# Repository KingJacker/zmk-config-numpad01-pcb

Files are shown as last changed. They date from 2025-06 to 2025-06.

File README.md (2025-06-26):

# NumPad01 - PCB

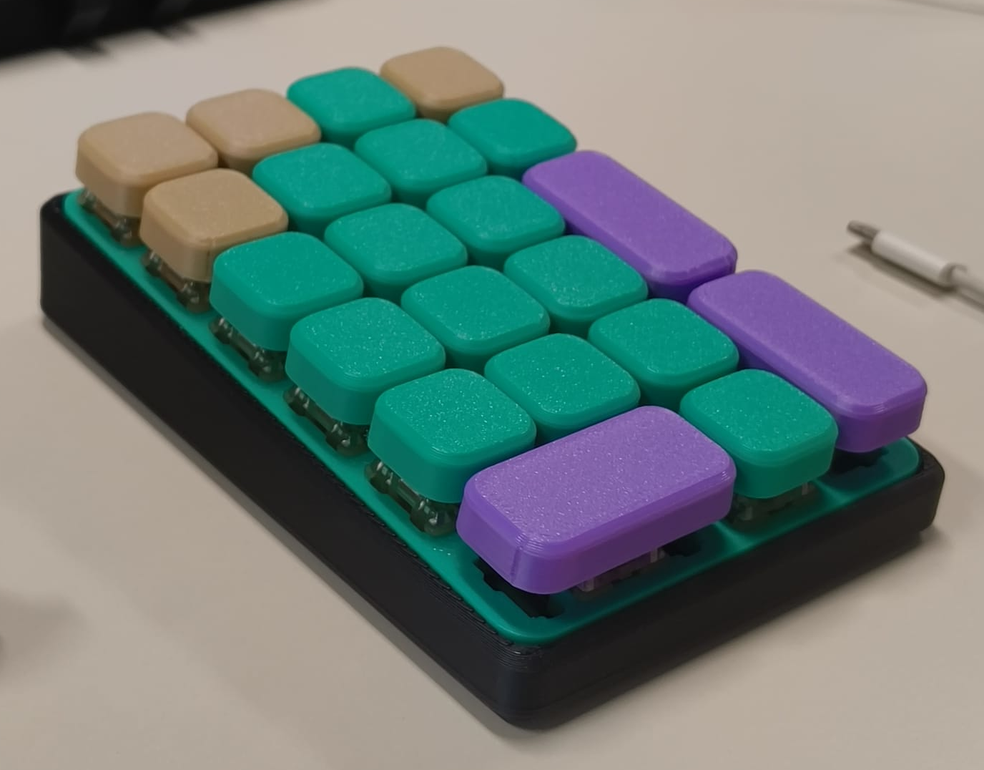
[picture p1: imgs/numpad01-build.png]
Example Build


This Repository outlines the requirements to build a custom Keyboard with an expanded Numpad layout.

## Hardware
This Keyboard is built using the NiceNanoV2 NRF Module to leverage its Bluetooth capabilities.

It is possible to Handwire this keyboard. Altough it was deisgned with a PCB in mind.

The KiCAD files can be found in [Numpad1](/Numpad1/).
The PCB is designed to use MX Hotswap sockets.

### Key Layout
The expanded Numpad layout looks as follows.\
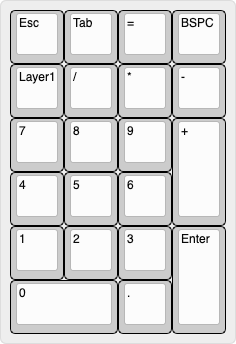
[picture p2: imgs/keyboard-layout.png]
Key Layout


### Wiring
In the following Diagram it is described which pins of the NiceNanoV2 are to be soldered to the Pads on the PCB.
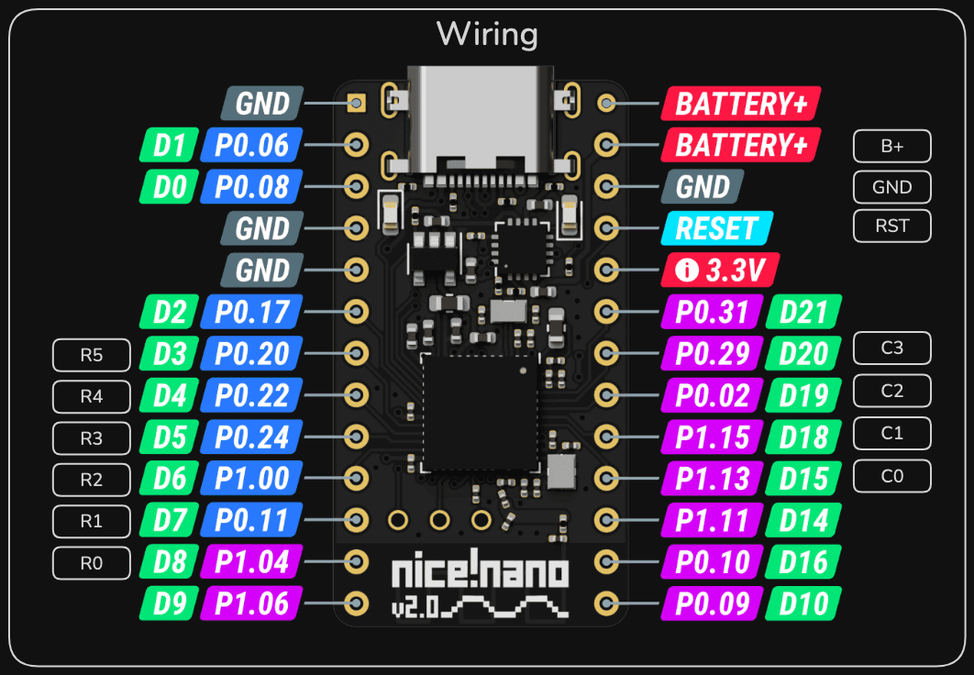
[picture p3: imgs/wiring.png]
Wiring Diagram


### Enclosure
I have deisgned a very slim Case for the PCB with just enough space for a small LiPo. You can find the OnShape Project at this [Link](https://cad.onshape.com/documents/f554f5fd452e23ddbeb69b48/w/c72bd622fd985e9e9cbd8d4f/e/263bace952513a244bd67565) or checkout the STEP files in [CAD/case](CAD/case).

###  Keycaps
This Keyboard has 21 Keys in Total.
| Amount | Type |
| --- |----- |
| 18 | 1u |
| 3 | 2u |

Custom Keycaps were designed for this project, while 3D printed Keycaps may not be optimal they surely look good.

You can find the OnShape Project at this [Link](https://cad.onshape.com/documents/af3d93fce92099b4708cc048/w/839bc3040b2b1ff49a4ff1b0/e/539817a75a59442267b910fb). Since I made multiple versions I won't upload them here.

## Firmware
To utilize the full Bluetooth capabilites of the NiceNanoV2 the ZMK firmware was used. This the Keymap of this config can be changed using [Nick's Keymap Editor](https://nickcoutsos.github.io/keymap-editor/).

You can find the latest firmware on the [Releases](https://github.com/KingJacker/zmk-config-numpad01-pcb/releases/tag/release) Page.

### Flashing
If you are starting out and haven't falshed anything to the NiceNanoV2, you need to short the RESET pin to GND twice in short succession while plugged in via USB C. 

The red light will Blink and a drive will appear on your computer with the name "NiceNanoV2". Simply drag the firmware file into drive. 

That's it, the drive will disappear and the NiceNanoV2 will reboot.

Once you have flashed this firmware you can always access the bootloader to update the firmware by pressing the Layer 1 Key and Plus at the same time.

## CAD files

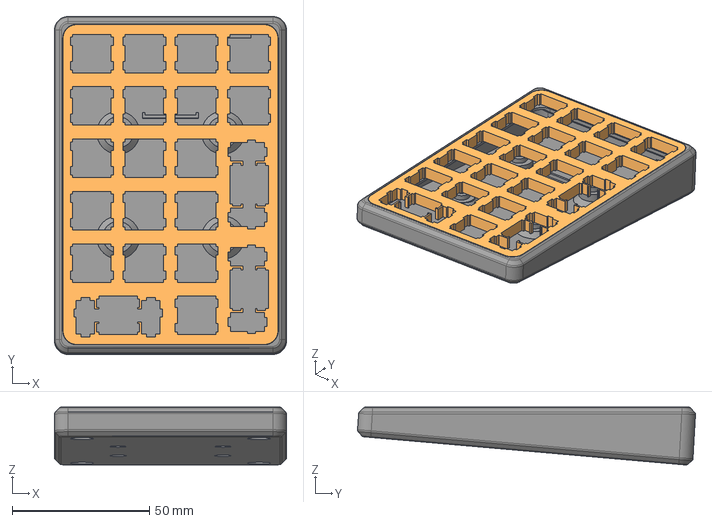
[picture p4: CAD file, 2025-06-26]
CAD/NumPad01-Case.step
84.4 x 122.9 x 21.1 mm
Plate

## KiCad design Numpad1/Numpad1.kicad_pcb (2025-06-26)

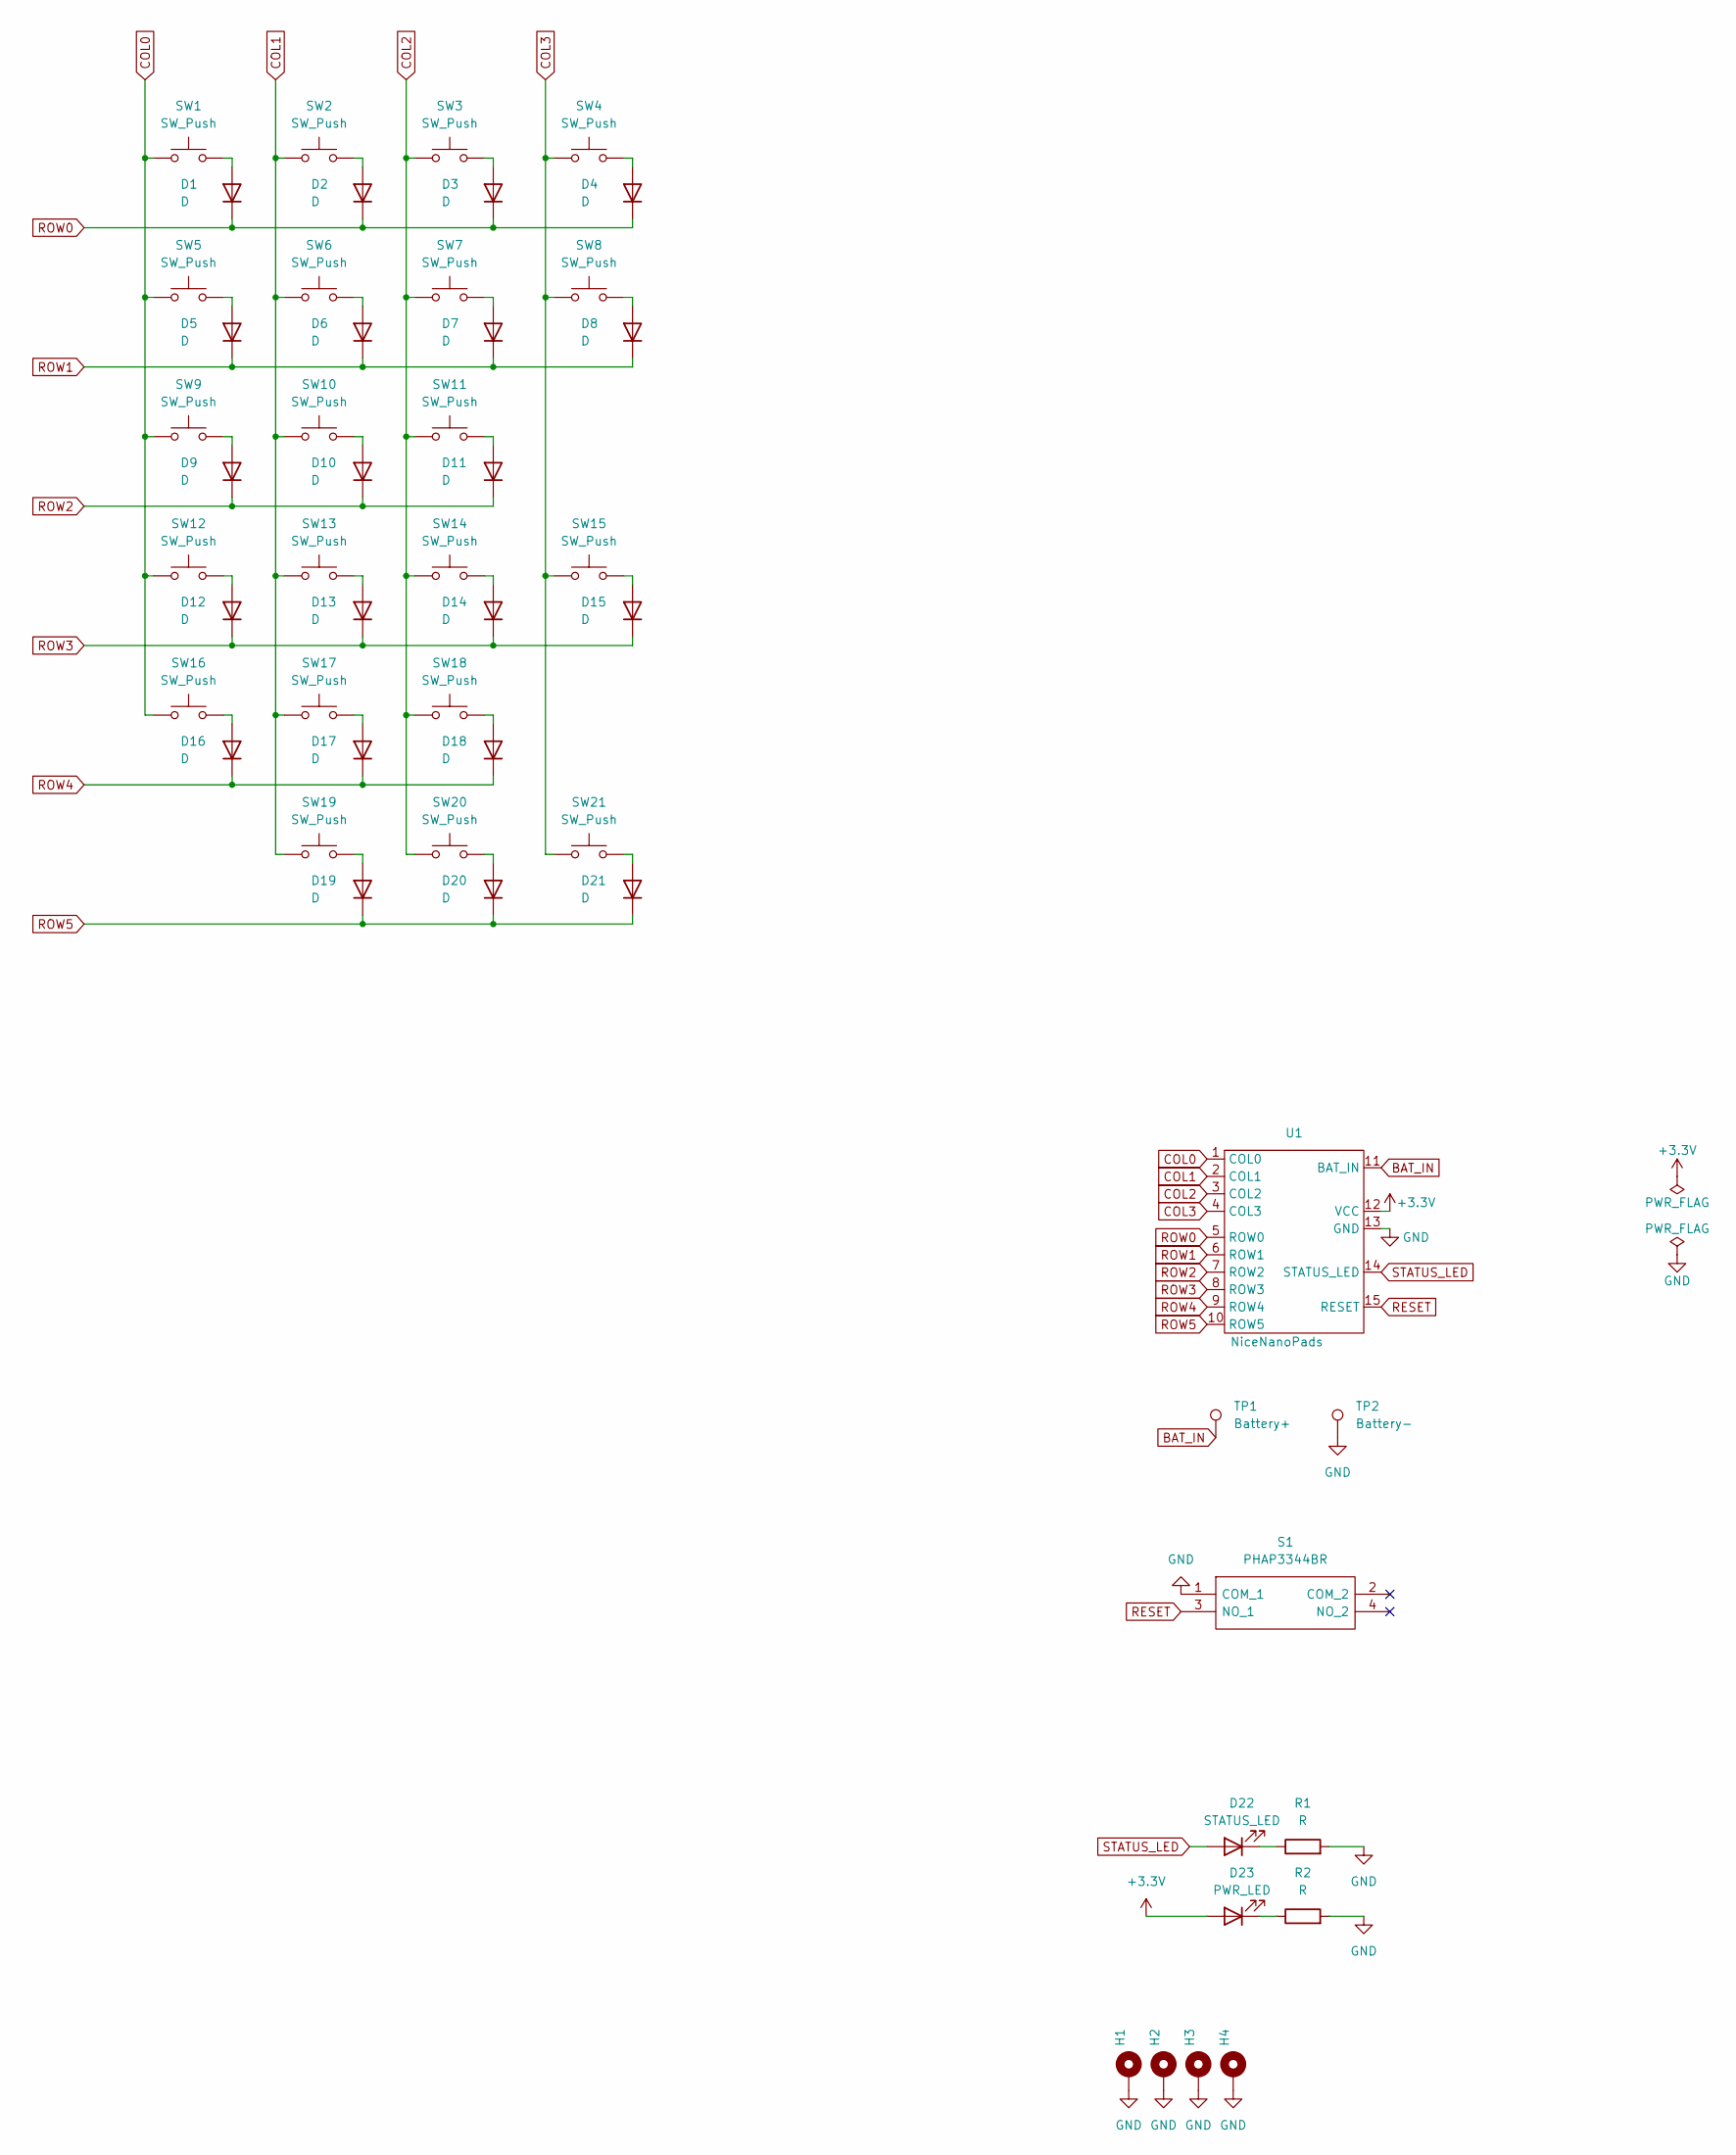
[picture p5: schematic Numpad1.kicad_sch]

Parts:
D1, D2, D3, D4, D5, D6, D7, D8, D9, D10, D11, D12, D13, D14, D15, D16, D17, D18, D19, D20, D21: D; D_SOD-123
D22: STATUS_LED; LED_0805_2012Metric_Pad1.15x1.40mm_HandSolder
D23: PWR_LED; LED_0805_2012Metric_Pad1.15x1.40mm_HandSolder
H1, H2, H3, H4: MountingHole_Pad; MountingHole_3.2mm_M3_DIN965_Pad
R1, R2: R; R_0805_2012Metric_Pad1.20x1.40mm_HandSolder
S1: PHAP3344BR; PTS526SM15SMTR2LFS; Mouser Part Number 642-PHAP3344BR
SW1, SW2, SW3, SW4, SW5, SW6, SW7, SW8, SW9, SW10, SW11, SW12, SW13, SW14, SW16, SW17, SW18, SW20: SW_Push; SW_Hotswap_Kailh_MX_1.00u
SW15, SW21: SW_Push; SW_Hotswap_Kailh_MX_2.00u_90deg
SW19: SW_Push; SW_Hotswap_Kailh_MX_2.00u
TP1: Battery+; TestPoint_Pad_D4.0mm
TP2: Battery-; TestPoint_Pad_D4.0mm
U1: NiceNanoPads

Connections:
+3.3V: D23.2 (A), U1.12 (VCC)
BAT_IN: TP1.1, U1.11 (BAT_IN); also elsewhere on the board
COL0: SW1.1, SW5.1, SW9.1, SW12.1, SW16.1, U1.1 (COL0)
COL1: SW2.1, SW6.1, SW10.1, SW13.1, SW17.1, SW19.1, U1.2 (COL1)
COL2: SW3.1, SW7.1, SW11.1, SW14.1, SW18.1, SW20.1, U1.3 (COL2)
COL3: SW4.1, SW8.1, SW15.1, SW21.1, U1.4 (COL3)
GND: H1.1, H2.1, H3.1, H4.1, R1.2, R2.2, S1.1 (COM_1), TP2.1, U1.13 (GND); also elsewhere on the board
unnamed: D1.2 (A), SW1.2
unnamed: D2.2 (A), SW2.2
unnamed: D3.2 (A), SW3.2
unnamed: D4.2 (A), SW4.2
unnamed: D5.2 (A), SW5.2
unnamed: D6.2 (A), SW6.2
unnamed: D7.2 (A), SW7.2
unnamed: D8.2 (A), SW8.2
unnamed: D9.2 (A), SW9.2
unnamed: D10.2 (A), SW10.2
unnamed: D11.2 (A), SW11.2
unnamed: D12.2 (A), SW12.2
unnamed: D13.2 (A), SW13.2
unnamed: D14.2 (A), SW14.2
unnamed: D15.2 (A), SW15.2
unnamed: D16.2 (A), SW16.2
unnamed: D17.2 (A), SW17.2
unnamed: D18.2 (A), SW18.2
unnamed: D19.2 (A), SW19.2
unnamed: D20.2 (A), SW20.2
unnamed: D21.2 (A), SW21.2
unnamed: D22.1 (K), R1.1
unnamed: D23.1 (K), R2.1
RESET: S1.3 (NO_1), U1.15 (RESET)
ROW0: D1.1 (K), D2.1 (K), D3.1 (K), D4.1 (K), U1.5 (ROW0)
ROW1: D5.1 (K), D6.1 (K), D7.1 (K), D8.1 (K), U1.6 (ROW1)
ROW2: D9.1 (K), D10.1 (K), D11.1 (K), U1.7 (ROW2)
ROW3: D12.1 (K), D13.1 (K), D14.1 (K), D15.1 (K), U1.8 (ROW3)
ROW4: D16.1 (K), D17.1 (K), D18.1 (K), U1.9 (ROW4)
ROW5: D19.1 (K), D20.1 (K), D21.1 (K), U1.10 (ROW5)
STATUS_LED: D22.2 (A), U1.14 (STATUS_LED)

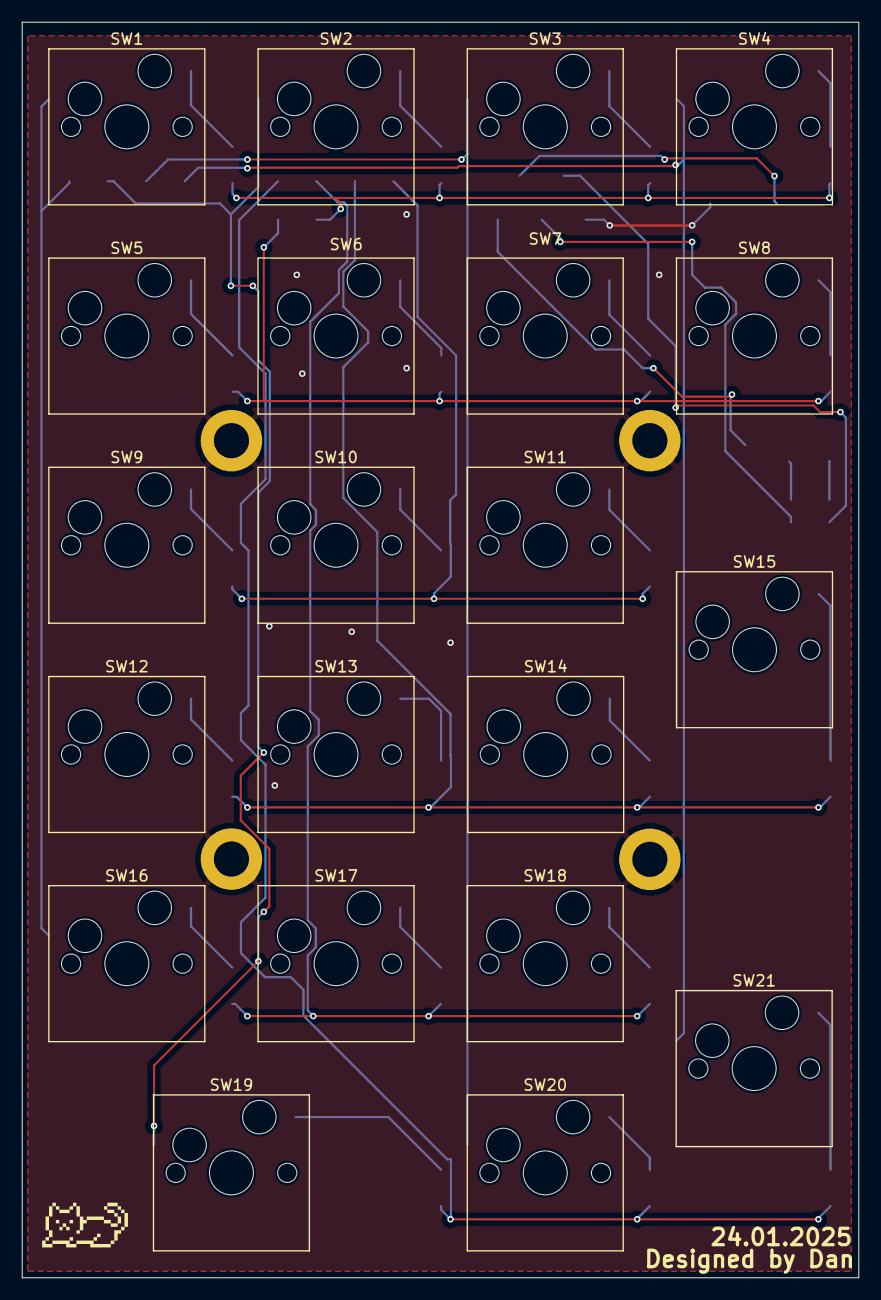
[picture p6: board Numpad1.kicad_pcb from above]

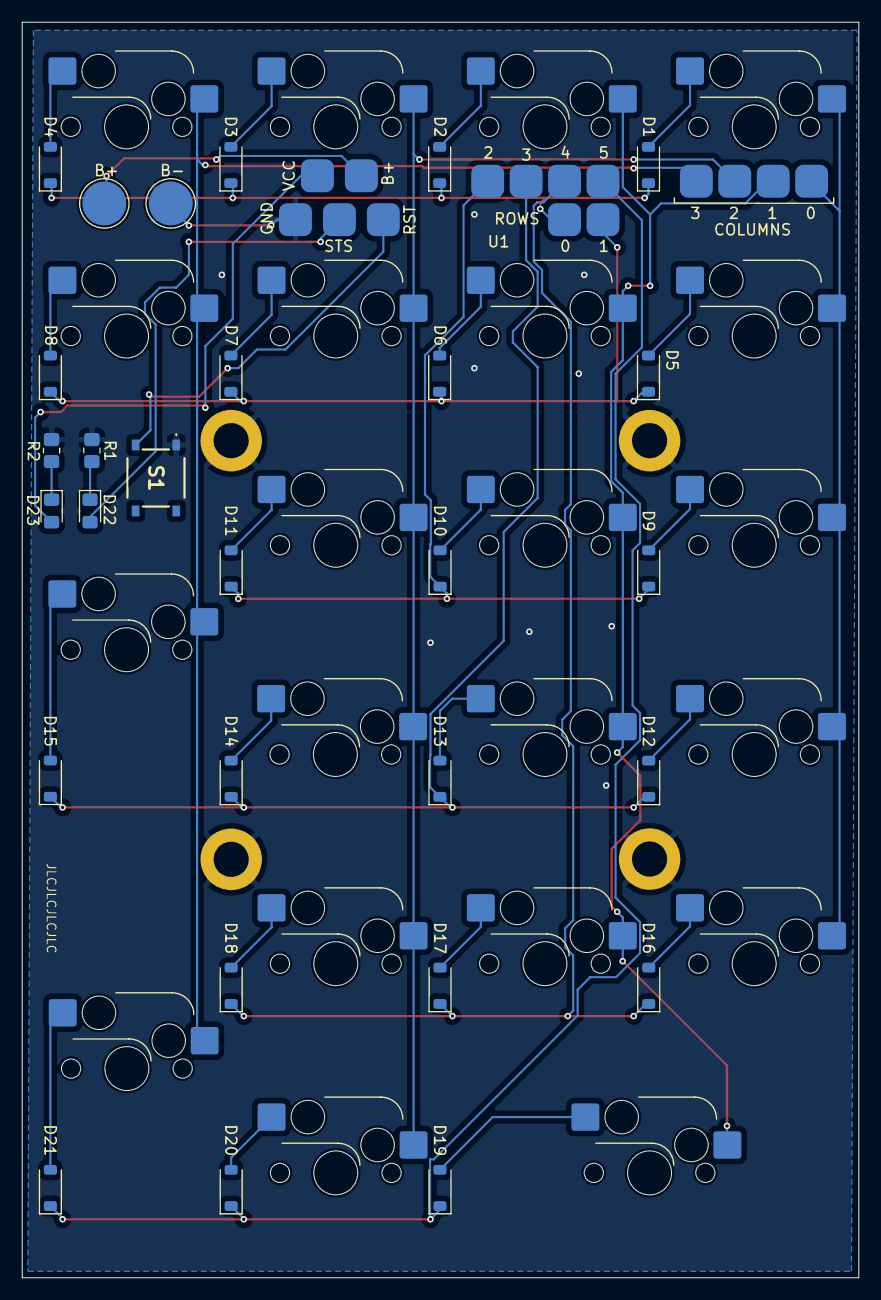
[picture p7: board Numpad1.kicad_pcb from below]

Board: 11 copper layers, 76.2 x 114.3 mm, 54 parts (29 on the bottom side), 38 nets.

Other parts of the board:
B+: Battery+; TestPoint_Pad_D4.0mm
B-: Battery-; TestPoint_Pad_D4.0mm

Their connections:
BAT_IN: B+.1; also elsewhere on the board
GND: B-.1; also elsewhere on the board

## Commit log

2025-02-10 fixed difference in wiring for 2u switches
2025-06-26 enable spi, setup for key configurator
2025-06-26 readme, imgs, kicad files, stepfile
    [NumPad01-Case.step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]
